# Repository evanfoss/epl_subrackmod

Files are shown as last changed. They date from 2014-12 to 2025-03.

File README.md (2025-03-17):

# EPL Subrack Module

Designed by Evan Foss
Primarily done in 2014
Documented 2025.03.12

## Purpose

This project is a template and parts meant to make designing projects for the <a href="https://github.com/EPL-Engineering/epl_subrack">EPL Subrack</a> easier. It's basically just a premade standardized PCB edge card used at the moment for power and a front panel template for use with the modules that fit that subrack.

|Quantity |Part Number |Vendor |Description |Application
|:--- |:--- |:--- |:--- |:---
|1 |EFP164A97F |Vector Electronics |Subrack Module Chassis |Subrack Module Chassis
|4 |N.A. |Generic |Binding Head Philips Drive Screws  |Used on the front panel
|4 |N.A. |Generic |Internal Toothed Lock Washers |Used on the front panel
|4 |N.A. |Generic |Cheese Head Screws |Use on the rear panel
|1 |N.A. |Custom Manufactured |Front Panel |Front Panel
|1 |N.A. |Custom Manufactured |Edge Card PCB |Rear Interconnect with subrack
|1 |0022122064 |Molex |6 pin right angle connector |Analog Power
|1 |0022122034 |Molex |3 pin right angle connector |Digital (aka noisy) Power

As the intention is to keep the modules in use for many years as projects are built and retired recycling the housing's changing the screws from the stock ones is important.

## Design

The circuit design is very simple because this is just an adapter.

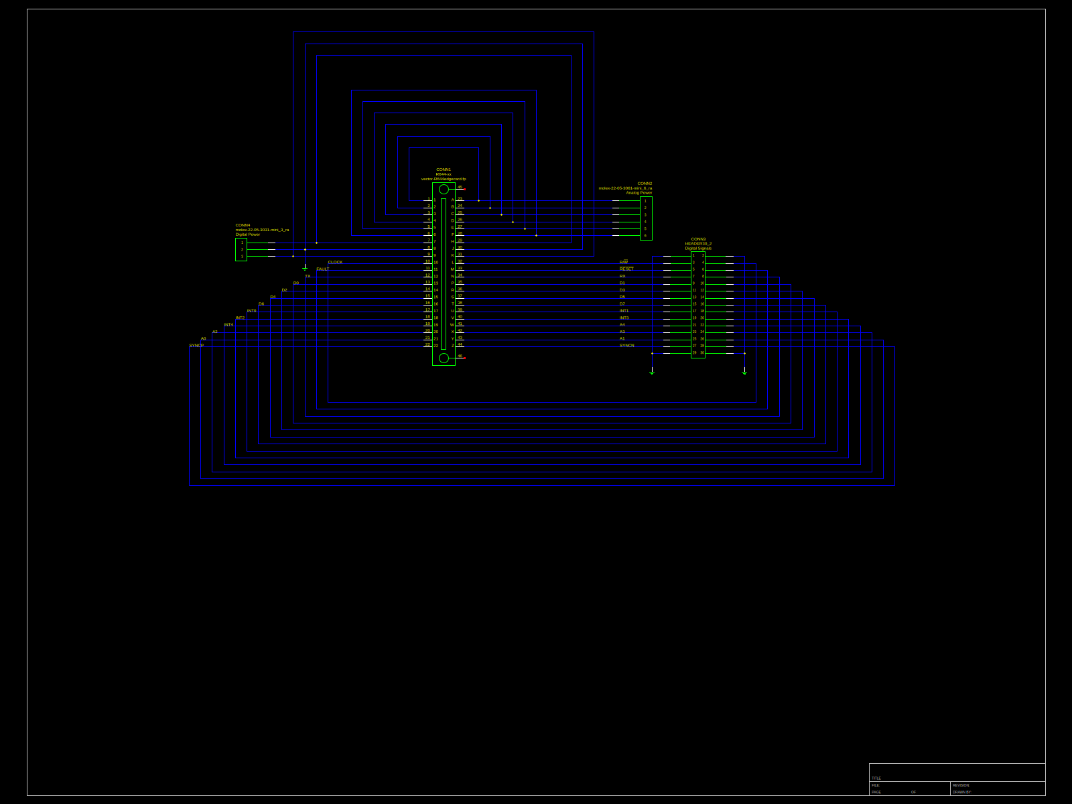
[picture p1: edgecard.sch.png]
Image of the schematic for the PCB showing connectors and the edge card wired together quite predictably.
| 
|:---------------
| Schematic

Note there is another schematic labeled "<a href="hidden-magic.sch.png">hidden-magic</a>" but it's empty. It is just part of my standard template for drafting PCB.

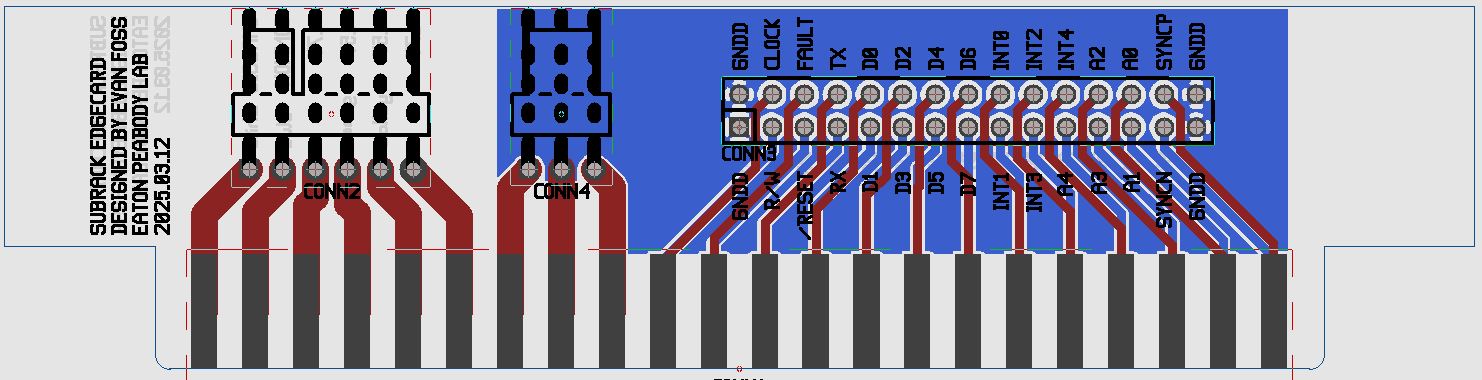
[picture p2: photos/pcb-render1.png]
The layout is uninspired honestly but it's not meant to be an artistic expression.
| 
|:---------------
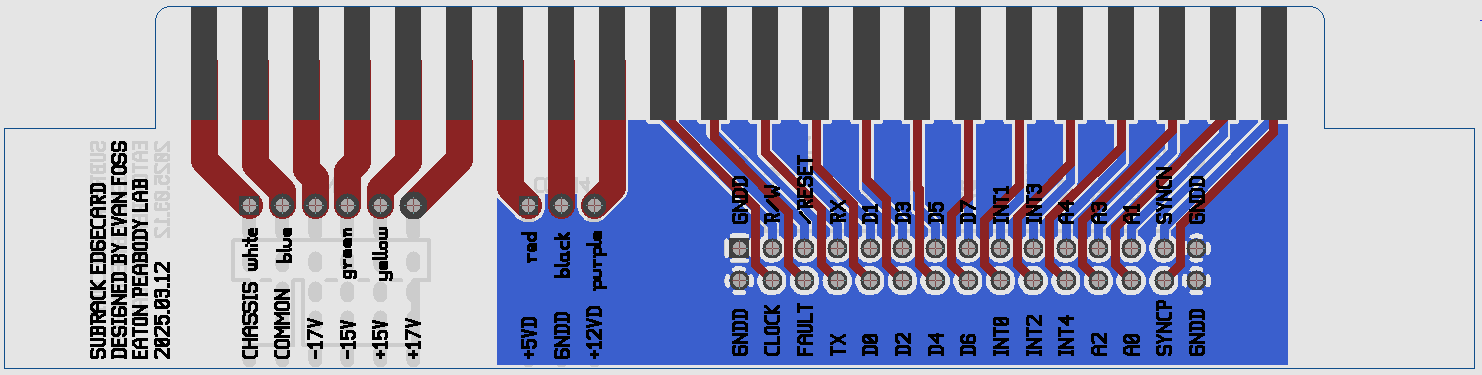
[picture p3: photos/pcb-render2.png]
| 
| PCB Layout

| <a href="photos/IMG_3226.JPG">The image shows the PCB in the 2nd of the small tracks from what would be left if oriented vertically.</a>
|:---------------
| <a href="photos/IMG_3227.JPG">The image clarifies that the power connections are at the top of the module.</a>
| Mechanical Alignment of the rear PCB. The left (power connection end) is the side that goes up.

The alignment of the rear PCB is critical for a few reasons.
 1. We don't want the PCB centered as that could lead to someone inserting a module upside down and burning it up.
 2. We don't want the PCB to come loose and slide into the backplane connector on an angle and short out or partially connect.
 3. We depend on the alignment of 4 or 5 modules in the rack during it's assembly to align the backplane.
 4. I hate the sound of things rattling in a completed device.

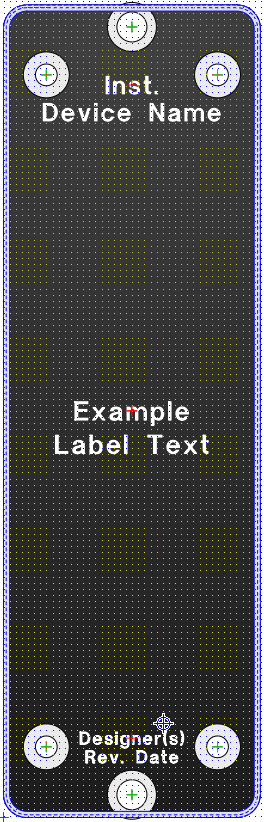
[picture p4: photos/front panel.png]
The front panel rendered by front panels express software showing 4 mounting holes for the extrusions and 2 mounting holes to secure the module into the subrack.
| 
| :---------------
| Front Panel template.

The front panel template has a few important features that the standard included front panel does not.
 1. The screw outlines are machined down to remove the anodizing from under the lockwashers so they make proper electrical contact for grounding.
 2. I rounded the corners so that when you insert or extract a module they don't risk cutting your hands.
 3. The added text is suggested font face and size for the institution of the designer's, device name, connection & switch labels, and designer initials/name at the bottom and revision date.

Observe the front panel has a bottom hole which the current subracks do not use but the original ones did.

## Future

This is a mature design. All that really needs to happen is for the digital connections in the module to see some more use. I have not yet specified a connector for that area but it should be keyed and probably right angle. Those pin allocations may evolve over time but they should *never* be made module specific.

One change I would like to make would be to bevel the PCB card edge but not every PCB fabrication facility does this and we are not inserting and extracting modules that frequently.

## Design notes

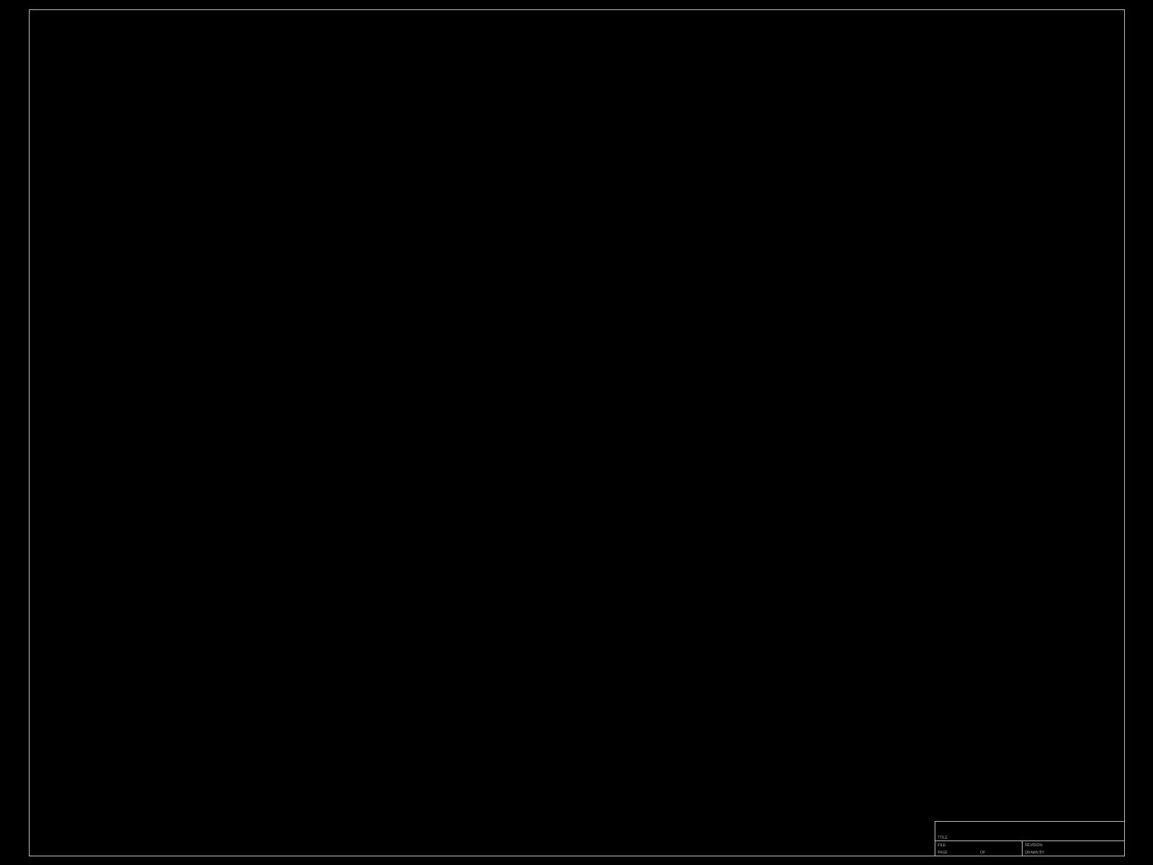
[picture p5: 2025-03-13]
hidden-magic.sch.png

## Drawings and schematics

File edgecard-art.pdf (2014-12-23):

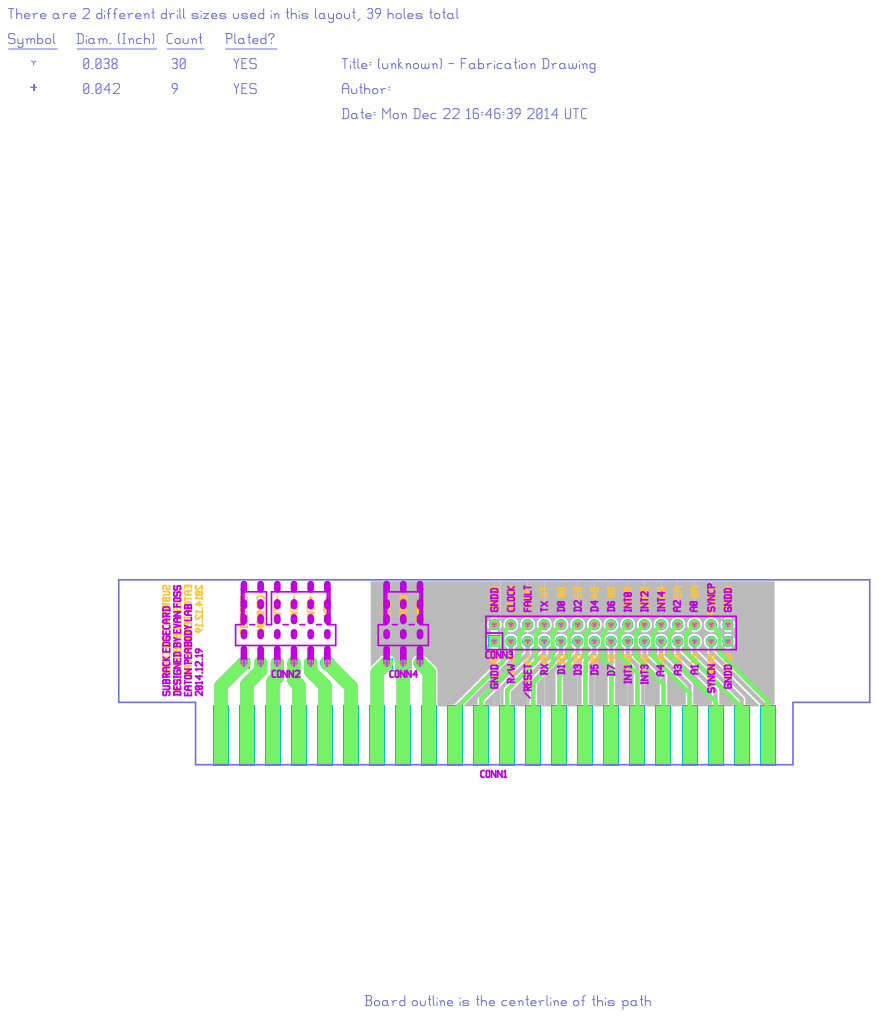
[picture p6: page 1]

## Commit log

2014-12-23 initial commit prototype status
    [edgecard-art.bottom.gbr, edgecard-art.bottommask.gbr, edgecard-art.bottompaste.gbr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]
2015-01-20 revised to improve alignment of edge card in backplane connector. also editorialize my desks 3rd code brown
    [edgecard-art.bottom.gbr, edgecard-art.bottommask.gbr, edgecard-art.bottompaste.gbr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]
2021-05-04 fix: the packaged version here before had the digital lines shorted?!
    [edgecard-art.gbl, edgecard-art.gbp, edgecard-art.gbs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]
2025-03-13 add: readme now includes renderings of the pcb
2025-03-13 add: readme now includes renderings of the pcb images
2025-03-13 add: readme schematics
2025-03-15 add: readme now shows mechanical alignment of the rear pcb
2025-03-15 add: readme more on the connectors
2025-03-15 add: readme more on schematics
